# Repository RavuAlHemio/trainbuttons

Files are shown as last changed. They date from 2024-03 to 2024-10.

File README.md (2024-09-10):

# trainbuttons

Two boards providing buttons for controlling a train (simulator).

The buttons are provided by keyboard key switches (Cherry MX or compatible). The two boards are to be interconnected via a repurposed HDMI cable; the left board is then connected via USB-C to the computer.

The button layout is inspired by the results of the EUDDplus (European Driver's Desk plus) project and UIC 612. The icons are reconstructed from those in EN 16186-2. The buttons chosen are those supported, or expected to be supported, by the Zusi simulator.

The design does not include throttle or brake levers; potentiometer-based solutions are available from [Stillertec](https://fahrpult.com/).

The default firmware lets the device appear as a HID gamepad device with zero axes and 21 buttons. A debug pin header is provided on the board to allow installation of other firmware.

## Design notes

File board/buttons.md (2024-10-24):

| button | switch | µC pin | GPIO  | ADC channel | control |
| --- | --- | --- | ----- | ---:| ---:|
| NTC_ACK | SW203  | 12 | PA1 | | button 1  |
| HORN | SW306  | 13 | PA2 | | button 2  |
| BELL | SW307  | 14 | PA3 | | button 3  |
| TDIR_DN | SW305  | 15 | PA4 | | button 4  |
| BRAKE_SCHG | SW308  | 18 | PA7 | | button 5  |
| DOOR_OPEN  | SW211  | 37 | PA15  | | button 6  |
| TDIR_UP | SW304  | 20 | PB1 | | button 7  |
| HEADLIGHT  | SW303  | 21 | PB2 | | button 8  |
| DOOR_CLSE  | SW212  | 42 | PB3 | | button 9  |
| DOOR_LEFT  | SW209  | 43 | PB4 | | button 10 |
| MCB_OFF | SW208  | 44 | PB5 | | button 11 |
| EMERG | SW213  | 45 | PB6 | | button 12 |
| ETCS_ACK | SW204  | 46 | PB7 | | button 13 |
| NTC_OVR | SW201  | 47 | PB8 | | button 14 |
| NTC_RLS | SW202  | 48 | PB9 | | button 15 |
| BRAKE_RLS  | SW302  | 22 | PB10  | | button 16 |
| SAND | SW301  | 23 | PB11  | | button 17 |
| MCB_ON | SW207  | 38 | PD0 | | button 18 |
| PANTO_UP | SW205  | 39 | PD1 | | button 19 |
| PANTO_DN | SW206  | 40 | PD2 | | button 20 |
| DOOR_RGHT  | SW210  | 41 | PD3 | | button 21 |
| PEDAL_ANA  | J201 | 17 | PA6 | 6 | X axis |

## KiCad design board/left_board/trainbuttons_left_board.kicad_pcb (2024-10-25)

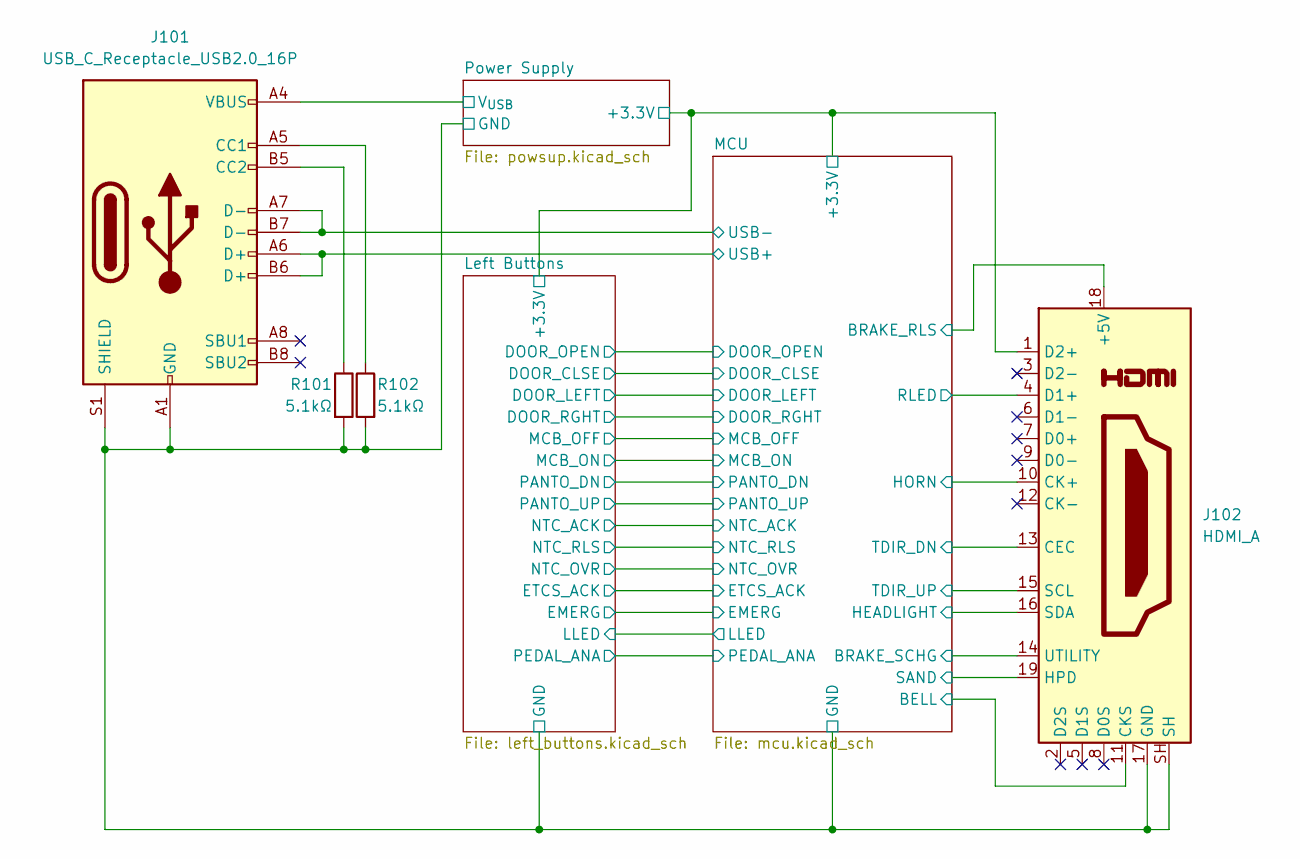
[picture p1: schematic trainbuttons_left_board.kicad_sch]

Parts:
J101: USB_C_Receptacle_USB2.0_16P; USB_C_Receptacle_G-Switch_GT-USB-7010ASV; LCSC C2988369
J102: HDMI_A; HDMI_A_Molex_208658-1001_Horizontal; LCSC C2858275
R101, R102: 5.1kΩ; R_0402_1005Metric; LCSC C25905

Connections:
/Left Buttons/+3.3V: J102.1 (D2+); also elsewhere on the board
/Left Buttons/GND: J101.A1 (GND), J101.A12 (GND), J101.B1 (GND), J101.B12 (GND), J101.S1 (SHIELD), J102.17 (GND), J102.SH, R101.2, R102.2; also elsewhere on the board
/MCU/BELL: J102.11 (CKS); also elsewhere on the board
/MCU/BRAKE_RLS: J102.18 (+5V); also elsewhere on the board
/MCU/BRAKE_SCHG: J102.14 (UTILITY); also elsewhere on the board
/MCU/HEADLIGHT: J102.16 (SDA); also elsewhere on the board
/MCU/HORN: J102.10 (CK+); also elsewhere on the board
/MCU/RLED: J102.4 (D1+); also elsewhere on the board
/MCU/SAND: J102.19 (HPD); also elsewhere on the board
/MCU/TDIR_DN: J102.13 (CEC); also elsewhere on the board
/MCU/TDIR_UP: J102.15 (SCL); also elsewhere on the board
/MCU/USB+: J101.A6 (D+), J101.B6 (D+); also elsewhere on the board
/MCU/USB-: J101.A7 (D-), J101.B7 (D-); also elsewhere on the board
/Power Supply/V_{USB}: J101.A4 (VBUS), J101.A9 (VBUS), J101.B4 (VBUS), J101.B9 (VBUS); also elsewhere on the board
unnamed: J101.A5 (CC1), R102.1
unnamed: J101.B5 (CC2), R101.1

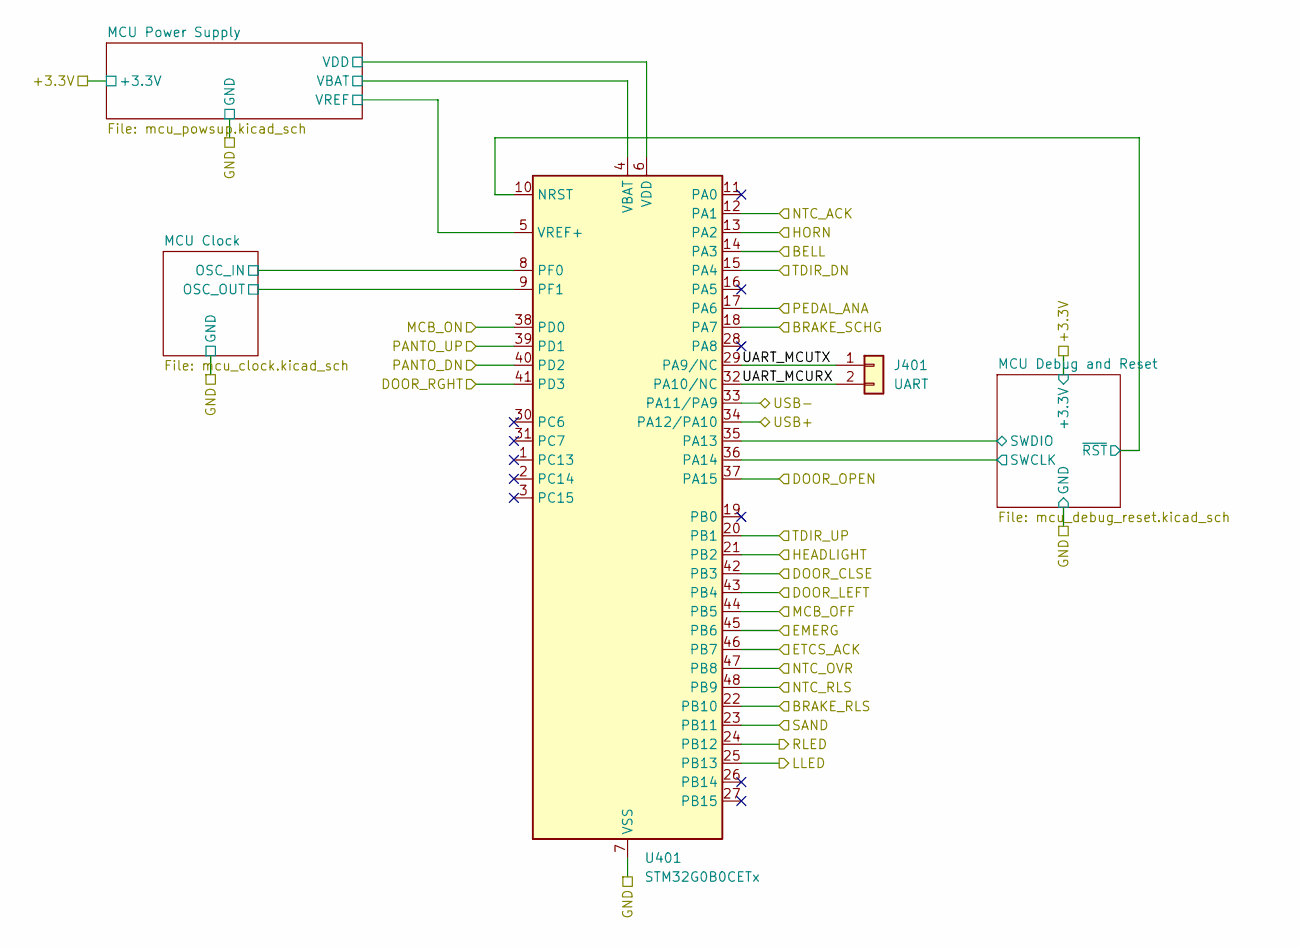
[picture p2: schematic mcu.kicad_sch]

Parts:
J401: UART; PinHeader_1x02_P2.54mm_Vertical_SMD_Pin1Left; LCSC C5160785
U401: STM32G0B0CETx; LQFP-48_7x7mm_P0.5mm; LCSC C2826978

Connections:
/Left Buttons/+3.3V: U401.4 (VBAT), U401.6 (VDD); also elsewhere on the board
/Left Buttons/DOOR_CLSE: U401.42 (PB3); also elsewhere on the board
/Left Buttons/DOOR_LEFT: U401.43 (PB4); also elsewhere on the board
/Left Buttons/DOOR_OPEN: U401.37 (PA15); also elsewhere on the board
/Left Buttons/DOOR_RGHT: U401.41 (PD3); also elsewhere on the board
/Left Buttons/EMERG: U401.45 (PB6); also elsewhere on the board
/Left Buttons/ETCS_ACK: U401.46 (PB7); also elsewhere on the board
/Left Buttons/GND: U401.7 (VSS); also elsewhere on the board
/Left Buttons/LLED: U401.25 (PB13); also elsewhere on the board
/Left Buttons/MCB_OFF: U401.44 (PB5); also elsewhere on the board
/Left Buttons/MCB_ON: U401.38 (PD0); also elsewhere on the board
/Left Buttons/NTC_ACK: U401.12 (PA1); also elsewhere on the board
/Left Buttons/NTC_OVR: U401.47 (PB8); also elsewhere on the board
/Left Buttons/NTC_RLS: U401.48 (PB9); also elsewhere on the board
/Left Buttons/PANTO_DN: U401.40 (PD2); also elsewhere on the board
/Left Buttons/PANTO_UP: U401.39 (PD1); also elsewhere on the board
/Left Buttons/PEDAL_ANA: U401.17 (PA6); also elsewhere on the board
/MCU/BELL: U401.14 (PA3); also elsewhere on the board
/MCU/BRAKE_RLS: U401.22 (PB10); also elsewhere on the board
/MCU/BRAKE_SCHG: U401.18 (PA7); also elsewhere on the board
/MCU/HEADLIGHT: U401.21 (PB2); also elsewhere on the board
/MCU/HORN: U401.13 (PA2); also elsewhere on the board
/MCU/MCU Clock/OSC_IN: U401.8 (PF0); also elsewhere on the board
/MCU/MCU Clock/OSC_OUT: U401.9 (PF1); also elsewhere on the board
/MCU/MCU Debug and Reset/SWCLK: U401.36 (PA14); also elsewhere on the board
/MCU/MCU Debug and Reset/SWDIO: U401.35 (PA13); also elsewhere on the board
/MCU/MCU Debug and Reset/~RST: U401.10 (NRST); also elsewhere on the board
/MCU/MCU Power Supply/VREF: U401.5 (VREF+); also elsewhere on the board
/MCU/RLED: U401.24 (PB12); also elsewhere on the board
/MCU/SAND: U401.23 (PB11); also elsewhere on the board
/MCU/TDIR_DN: U401.15 (PA4); also elsewhere on the board
/MCU/TDIR_UP: U401.20 (PB1); also elsewhere on the board
/MCU/UART_MCURX: J401.2, U401.32 (PA10/NC)
/MCU/UART_MCUTX: J401.1, U401.29 (PA9/NC)
/MCU/USB+: U401.34 (PA12/PA10); also elsewhere on the board
/MCU/USB-: U401.33 (PA11/PA9); also elsewhere on the board

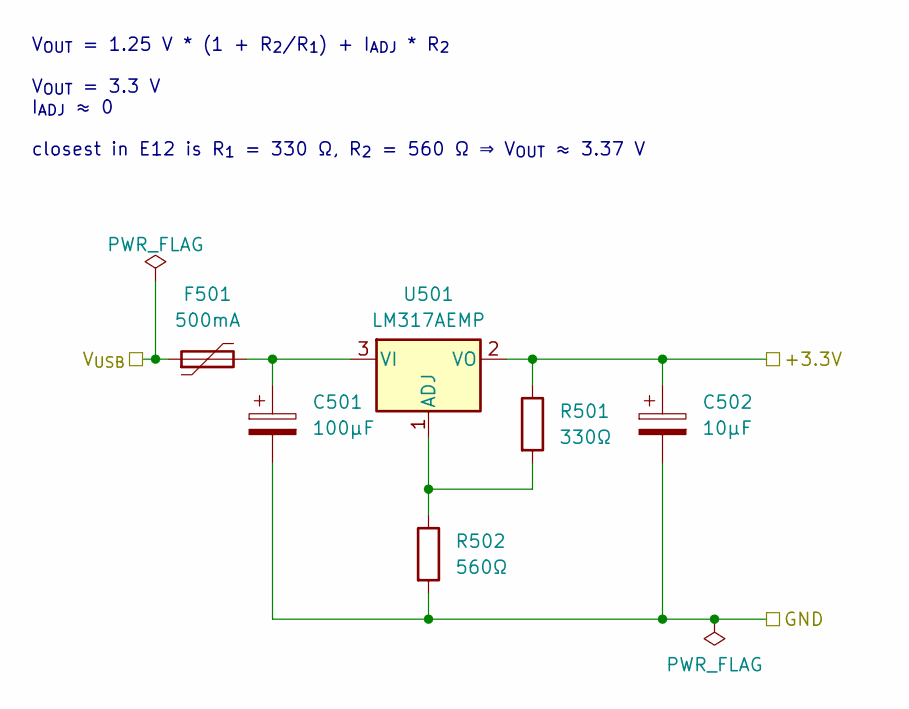
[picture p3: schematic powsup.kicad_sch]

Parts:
C501: 100µF; CP_EIA-3528-21_Kemet-B; LCSC C16133
C502: 10µF; CP_EIA-3216-18_Kemet-A; LCSC C7171
F501: 500mA; Fuse_0805_2012Metric; LCSC C2977522
R501: 330Ω; R_0603_1608Metric; LCSC C23138
R502: 560Ω; R_0603_1608Metric; LCSC C23204
U501: LM317AEMP; SOT-223-3_TabPin2; LCSC C33586

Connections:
/Left Buttons/+3.3V: C502.1, R501.1, U501.2 (VO); also elsewhere on the board
/Left Buttons/GND: C501.2, C502.2, R502.2; also elsewhere on the board
/Power Supply/V_{USB}: F501.1; also elsewhere on the board
unnamed: R501.2, R502.1, U501.1 (ADJ)
unnamed: C501.1, F501.2, U501.3 (VI)

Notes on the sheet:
V_{OUT} = 1.25 V * (1 + R_{2}/R_{1}) + I_{ADJ} * R_{2} V_{OUT} = 3.3 V I_{ADJ} ≈ 0 closest in E12 is R_{1} = 330 Ω, R_{2} = 560 Ω ⇒ V_{OUT} ≈ 3.37 V

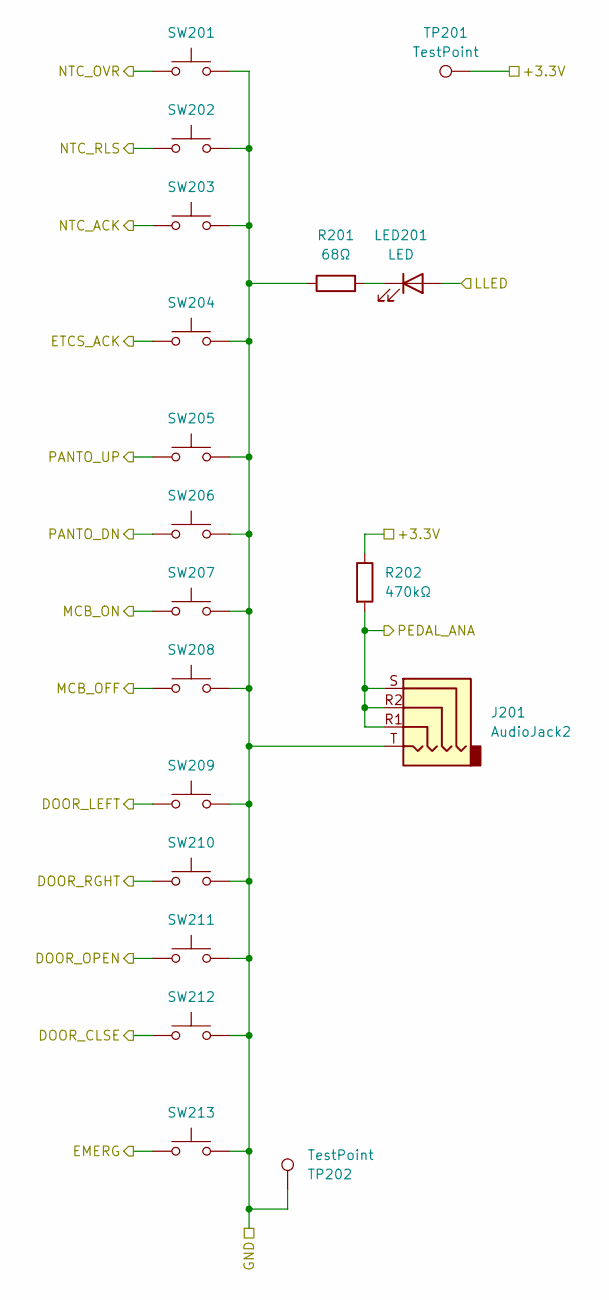
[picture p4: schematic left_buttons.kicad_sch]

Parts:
J201: AudioJack2; Jack_3.5mm_PJ320D_Horizontal; LCSC C431535
LED201: LED; LED_0805_2012Metric; LCSC C2296
R201: 68Ω; R_0805_2012Metric; LCSC C17802
R202: 470kΩ; R_0603_1608Metric; LCSC C23178
SW201, SW202, SW203, SW204, SW205, SW206, SW207, SW208, SW209, SW210, SW211, SW212, SW213: SW_Push; SW_Cherry_MX_1.00u_PCB
TP201, TP202: TestPoint; TestPoint_Pad_D1.0mm

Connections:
/Left Buttons/+3.3V: R202.1, TP201.1; also elsewhere on the board
/Left Buttons/DOOR_CLSE: SW212.1; also elsewhere on the board
/Left Buttons/DOOR_LEFT: SW209.1; also elsewhere on the board
/Left Buttons/DOOR_OPEN: SW211.1; also elsewhere on the board
/Left Buttons/DOOR_RGHT: SW210.1; also elsewhere on the board
/Left Buttons/EMERG: SW213.1; also elsewhere on the board
/Left Buttons/ETCS_ACK: SW204.1; also elsewhere on the board
/Left Buttons/GND: J201.T, R201.1, SW201.2, SW202.2, SW203.2, SW204.2, SW205.2, SW206.2, SW207.2, SW208.2, SW209.2, SW210.2, SW211.2, SW212.2, SW213.2, TP202.1; also elsewhere on the board
/Left Buttons/LLED: LED201.2 (A); also elsewhere on the board
/Left Buttons/MCB_OFF: SW208.1; also elsewhere on the board
/Left Buttons/MCB_ON: SW207.1; also elsewhere on the board
/Left Buttons/NTC_ACK: SW203.1; also elsewhere on the board
/Left Buttons/NTC_OVR: SW201.1; also elsewhere on the board
/Left Buttons/NTC_RLS: SW202.1; also elsewhere on the board
/Left Buttons/PANTO_DN: SW206.1; also elsewhere on the board
/Left Buttons/PANTO_UP: SW205.1; also elsewhere on the board
/Left Buttons/PEDAL_ANA: J201.R1, J201.R2, J201.S, R202.2; also elsewhere on the board
unnamed: LED201.1 (K), R201.2

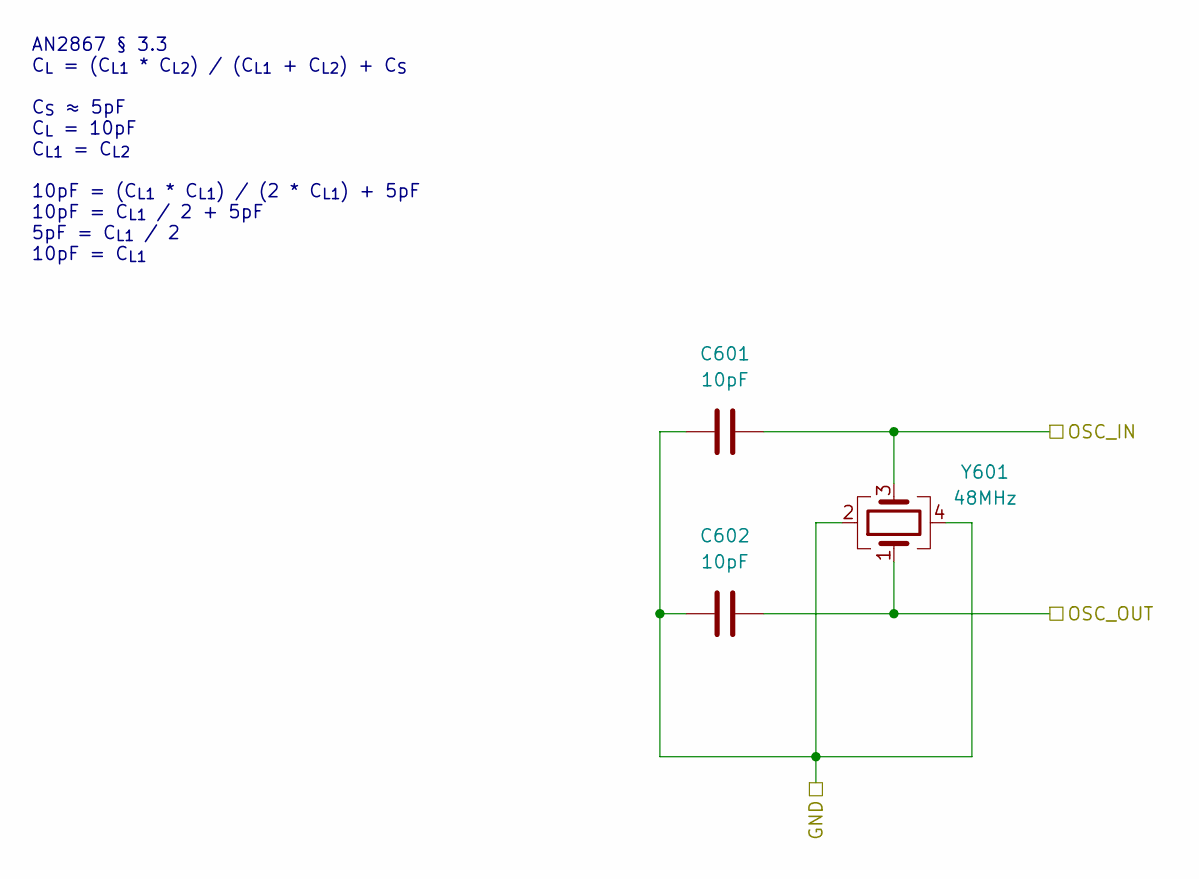
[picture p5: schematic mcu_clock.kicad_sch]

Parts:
C601, C602: 10pF; C_0402_1005Metric; LCSC C32949
Y601: 48MHz; Crystal_SMD_2016-4Pin_2.0x1.6mm; LCSC C648978

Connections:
/Left Buttons/GND: C601.1, C602.1, Y601.2, Y601.4; also elsewhere on the board
/MCU/MCU Clock/OSC_IN: C601.2, Y601.3; also elsewhere on the board
/MCU/MCU Clock/OSC_OUT: C602.2, Y601.1; also elsewhere on the board

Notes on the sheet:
AN2867 § 3.3 C_{L} = (C_{L1} * C_{L2}) / (C_{L1} + C_{L2}) + C_{S} C_{S} ≈ 5pF C_{L} = 10pF C_{L1} = C_{L2} 10pF = (C_{L1} * C_{L1}) / (2 * C_{L1}) + 5pF 10pF = C_{L1} / 2 + 5pF 5pF = C_{L1} / 2 10pF = C_{L1}

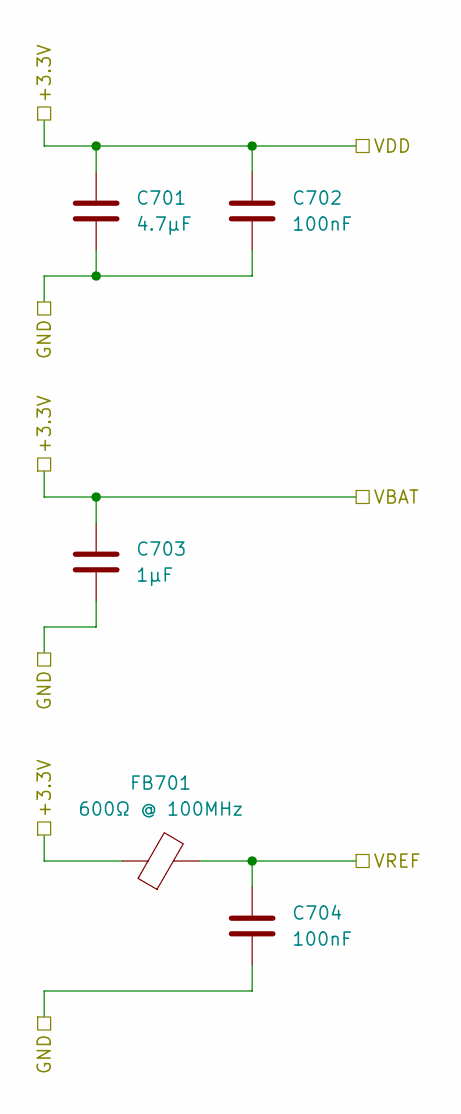
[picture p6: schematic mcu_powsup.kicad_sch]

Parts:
C701: 4.7μF; C_0402_1005Metric; LCSC C23733
C702, C704: 100nF; C_0402_1005Metric; LCSC C307331
C703: 1μF; C_0402_1005Metric; LCSC C52923
FB701: 600Ω @ 100MHz; L_0402_1005Metric; LCSC C560060

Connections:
/Left Buttons/+3.3V: C701.1, C702.1, C703.1, FB701.1; also elsewhere on the board
/Left Buttons/GND: C701.2, C702.2, C703.2, C704.2; also elsewhere on the board
/MCU/MCU Power Supply/VREF: C704.1, FB701.2; also elsewhere on the board

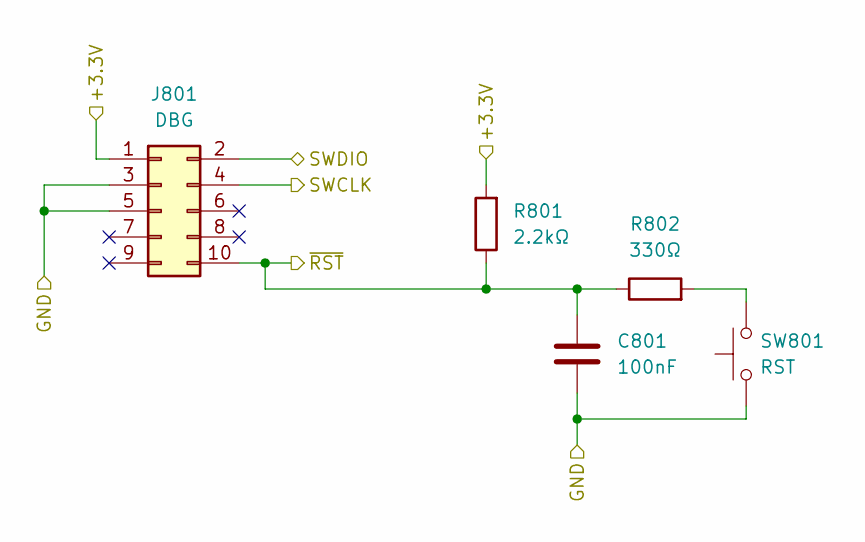
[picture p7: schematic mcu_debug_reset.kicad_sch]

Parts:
C801: 100nF; C_0402_1005Metric; LCSC C307331
J801: DBG; PinHeader_2x05_P1.27mm_Vertical_SMD; LCSC C5250218
R801: 2.2kΩ; R_0402_1005Metric; LCSC C25879
R802: 330Ω; R_0402_1005Metric; LCSC C25104
SW801: RST; SW_Push_1P1T_XKB_TS-1187A; LCSC C318884

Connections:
/Left Buttons/+3.3V: J801.1, R801.2; also elsewhere on the board
/Left Buttons/GND: C801.1, J801.3, J801.5, SW801.1; also elsewhere on the board
/MCU/MCU Debug and Reset/SWCLK: J801.4; also elsewhere on the board
/MCU/MCU Debug and Reset/SWDIO: J801.2; also elsewhere on the board
/MCU/MCU Debug and Reset/~RST: C801.2, J801.10, R801.1, R802.1; also elsewhere on the board
unnamed: R802.2, SW801.2

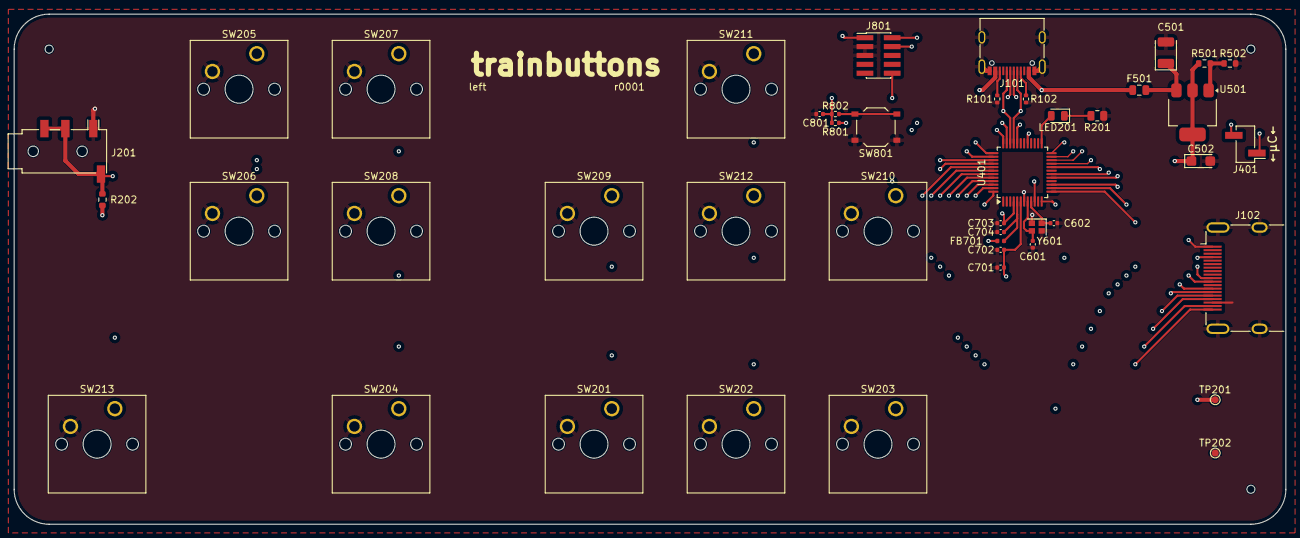
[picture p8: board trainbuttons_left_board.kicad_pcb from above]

Board: 4 copper layers, 182.0 x 73.0 mm, 44 parts (0 on the bottom side), 43 nets.

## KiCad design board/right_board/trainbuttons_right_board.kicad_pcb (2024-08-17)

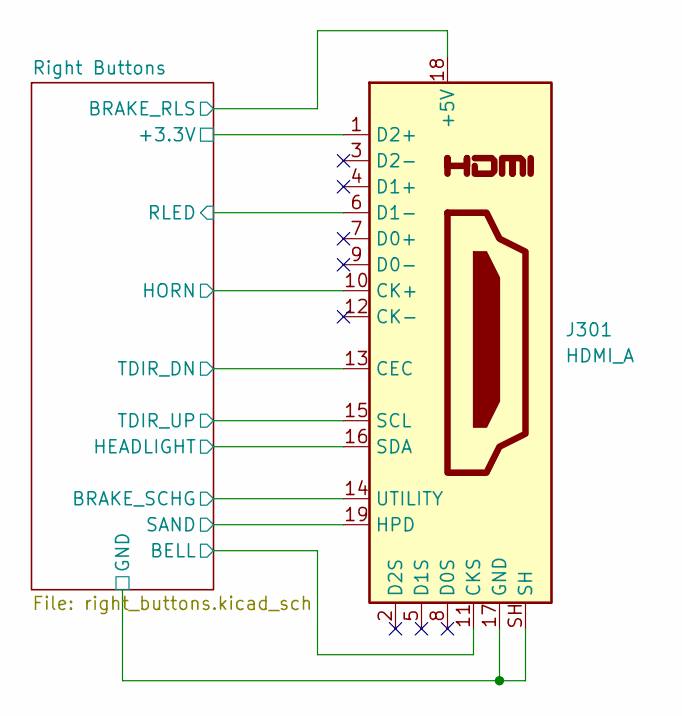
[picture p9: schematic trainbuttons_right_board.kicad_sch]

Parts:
J301: HDMI_A; HDMI_A_Molex_208658-1001_Horizontal; LCSC C2858275

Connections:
/Right Buttons/+3.3V: J301.1 (D2+); also elsewhere on the board
/Right Buttons/BELL: J301.11 (CKS); also elsewhere on the board
/Right Buttons/BRAKE_RLS: J301.18 (+5V); also elsewhere on the board
/Right Buttons/BRAKE_SCHG: J301.14 (UTILITY); also elsewhere on the board
/Right Buttons/GND: J301.17 (GND), J301.SH; also elsewhere on the board
/Right Buttons/HEADLIGHT: J301.16 (SDA); also elsewhere on the board
/Right Buttons/HORN: J301.10 (CK+); also elsewhere on the board
/Right Buttons/RLED: J301.6 (D1-); also elsewhere on the board
/Right Buttons/SAND: J301.19 (HPD); also elsewhere on the board
/Right Buttons/TDIR_DN: J301.13 (CEC); also elsewhere on the board
/Right Buttons/TDIR_UP: J301.15 (SCL); also elsewhere on the board

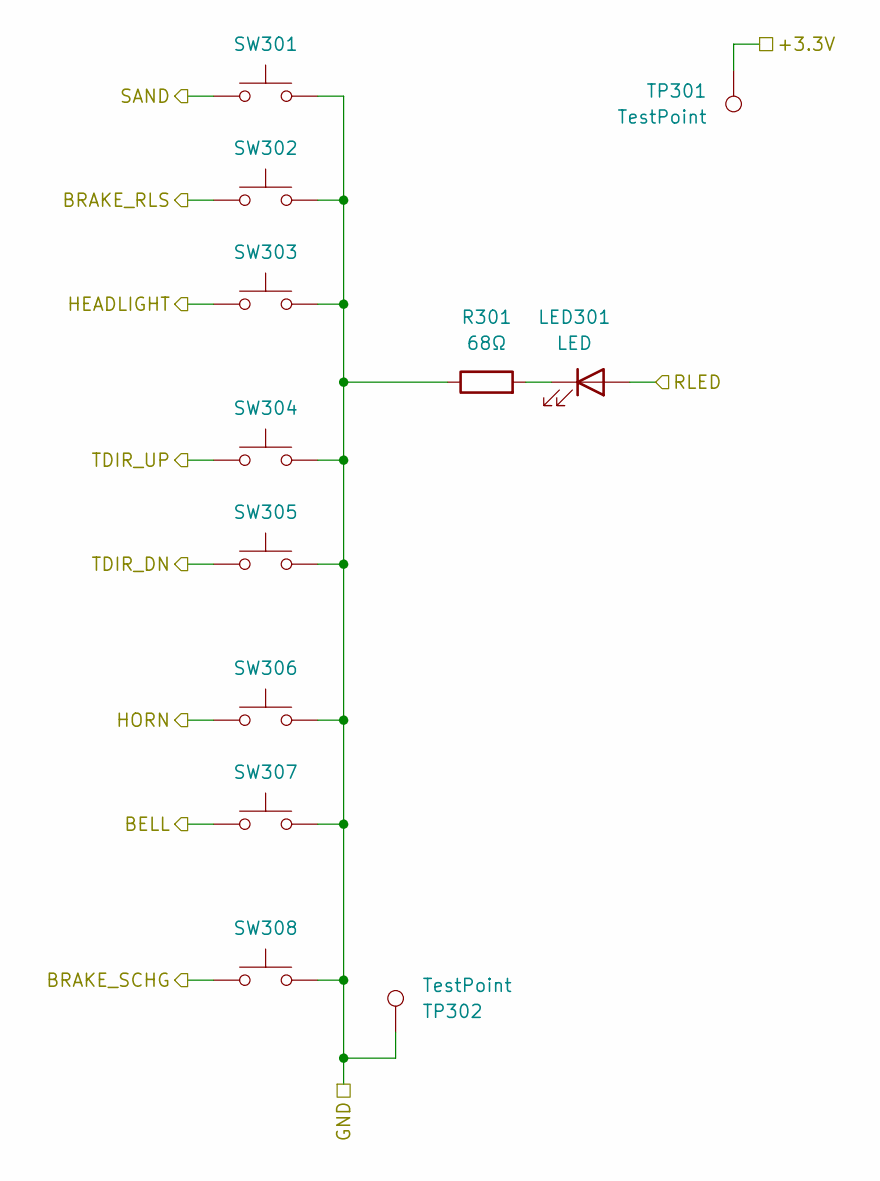
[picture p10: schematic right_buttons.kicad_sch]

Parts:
LED301: LED; LED_0805_2012Metric; LCSC C2296
R301: 68Ω; R_0805_2012Metric; LCSC C17802
SW301, SW302, SW303, SW304, SW305, SW306, SW307, SW308: SW_Push; SW_Cherry_MX_1.00u_PCB
TP301, TP302: TestPoint; TestPoint_Pad_D1.0mm

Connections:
/Right Buttons/+3.3V: TP301.1; also elsewhere on the board
/Right Buttons/BELL: SW307.1; also elsewhere on the board
/Right Buttons/BRAKE_RLS: SW302.1; also elsewhere on the board
/Right Buttons/BRAKE_SCHG: SW308.1; also elsewhere on the board
/Right Buttons/GND: R301.1, SW301.2, SW302.2, SW303.2, SW304.2, SW305.2, SW306.2, SW307.2, SW308.2, TP302.1; also elsewhere on the board
/Right Buttons/HEADLIGHT: SW303.1; also elsewhere on the board
/Right Buttons/HORN: SW306.1; also elsewhere on the board
/Right Buttons/RLED: LED301.2 (A); also elsewhere on the board
/Right Buttons/SAND: SW301.1; also elsewhere on the board
/Right Buttons/TDIR_DN: SW305.1; also elsewhere on the board
/Right Buttons/TDIR_UP: SW304.1; also elsewhere on the board
unnamed: LED301.1 (K), R301.2

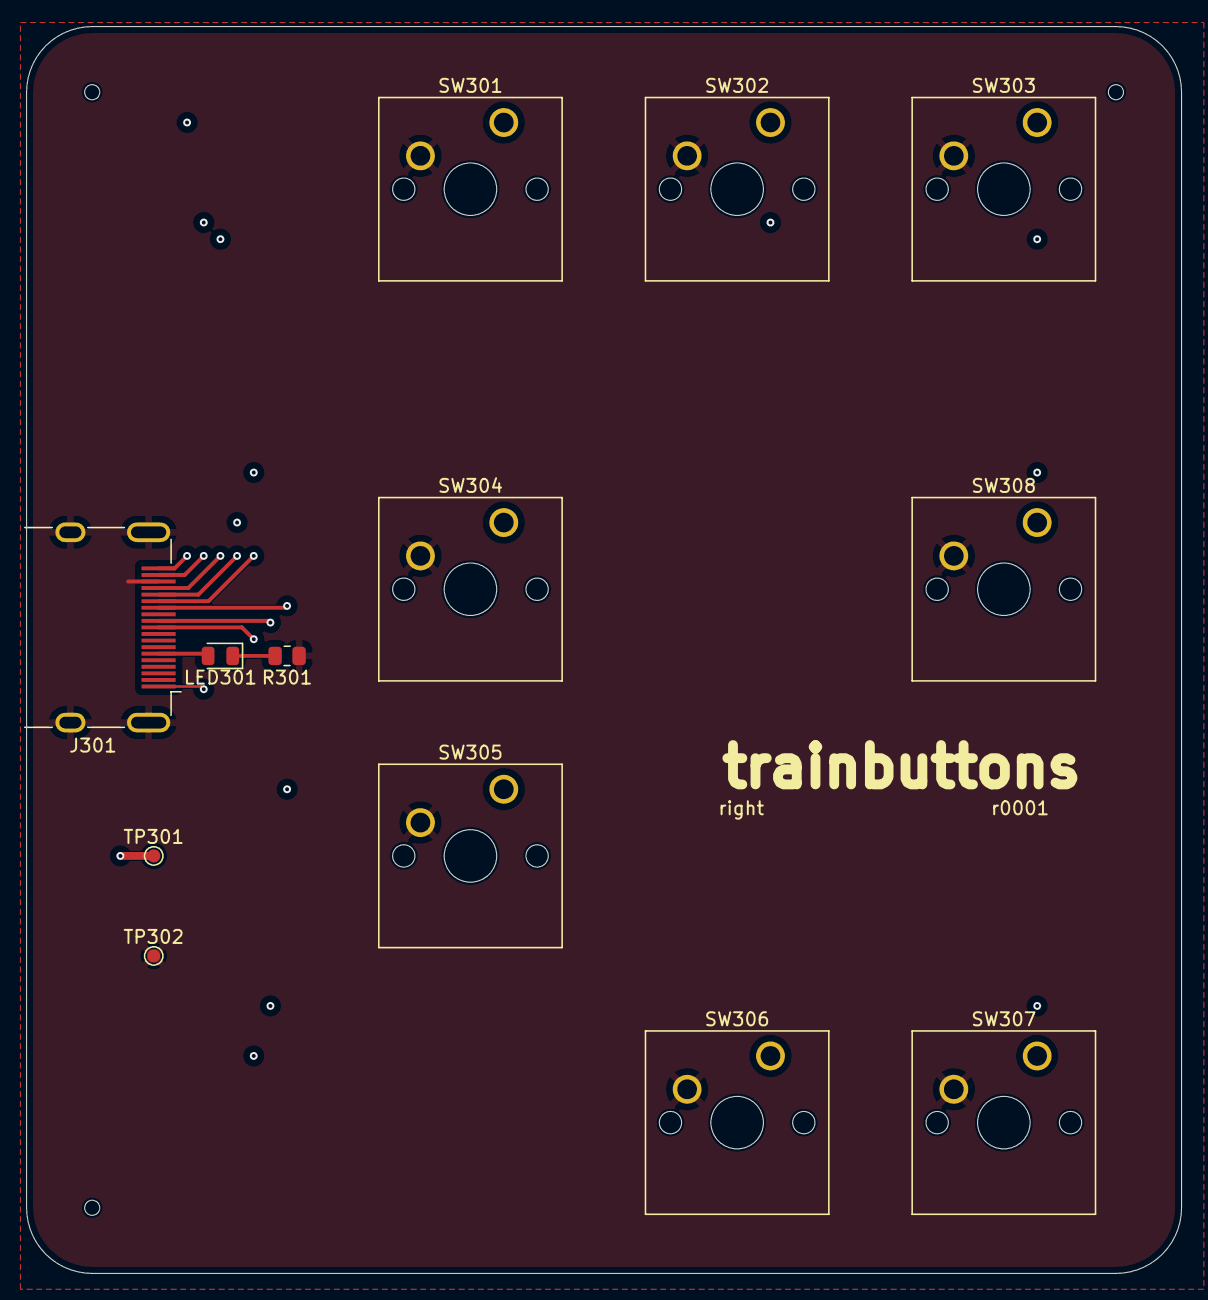
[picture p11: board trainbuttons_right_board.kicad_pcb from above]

Board: 4 copper layers, 88.0 x 95.0 mm, 13 parts (0 on the bottom side), 12 nets.

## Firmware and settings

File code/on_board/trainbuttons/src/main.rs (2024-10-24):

#![no_std]
#![no_main]


mod adc;
mod clock;
mod pins;
mod uart;
mod usb;


use core::panic::PanicInfo;

use cortex_m_rt::entry;
use stm32g0b0::Peripherals;


#[panic_handler]
fn panic_handler(_panic_info: &PanicInfo) -> ! {
    loop {
    }
}


#[inline(never)]
fn tell_gdb_to_return_from_this_function() {
    // address 4 (reset interrupt) is never 1
    const RESET_INTERRUPT_PTR: *const u32 = 0x0000_0004 as *const u32;
    loop {
        let isvp = unsafe { core::ptr::read_volatile(RESET_INTERRUPT_PTR) };
        if isvp == 1 {
            return;
        }
    }
}


#[entry]
fn main() -> ! {
    let peripherals = unsafe { Peripherals::steal() };

    crate::clock::set_up(&peripherals);

    // disable pulldowns
    peripherals.syscfg.cfgr1().modify(|_, w| w
        .ucpd1_strobe().set_bit() // disable pulldowns on PA8 and PB15
        .ucpd2_strobe().set_bit() // disable pulldowns on PD0 and PD2
    );

    // send clock to all relevant peripherals
    crate::adc::enable_peripheral_clocks(&peripherals);
    crate::pins::enable_peripheral_clocks(&peripherals);
    crate::uart::enable_peripheral_clocks(&peripherals);
    crate::usb::enable_peripheral_clocks(&peripherals);

    // reset all relevant peripherals
    crate::adc::start_reset(&peripherals);
    crate::pins::start_reset(&peripherals);
    crate::uart::start_reset(&peripherals);
    crate::usb::start_reset(&peripherals);
    // give it a bit to reset
    for _ in 0..64 {
        cortex_m::asm::nop();
    }
    crate::adc::stop_reset(&peripherals);
    crate::pins::stop_reset(&peripherals);
    crate::uart::stop_reset(&peripherals);
    crate::usb::stop_reset(&peripherals);
    // give it a bit to reinitialize
    for _ in 0..64 {
        cortex_m::asm::nop();
    }

    // set up pins (buttons and LEDs)
    crate::pins::set_up(&peripherals);

    // turn on LED on other board
    peripherals.gpiob.bsrr().write(|w| w
        .bs12().set_bit()
    );

    // set up ADC, UART and USB
    crate::adc::set_up(&peripherals);
    crate::uart::set_up(&peripherals);
    crate::usb::set_up(&peripherals);

    // send initial data via UART
    crate::uart::write_bytes(&peripherals, b"\r\nHi, world!\r\n");

    /*
    // disable USB IRQ so we can poke around
    cortex_m::peripheral::NVIC::mask(stm32g0b0::Interrupt::USB);
    tell_gdb_to_return_from_this_function();
    */

    loop {
        cortex_m::asm::wfe();
    }
}

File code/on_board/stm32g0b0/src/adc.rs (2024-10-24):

#[repr(C)]
#[doc = "Register block"]
pub struct RegisterBlock {
    isr: Isr,
    ier: Ier,
    cr: Cr,
    cfgr1: Cfgr1,
    cfgr2: Cfgr2,
    smpr: Smpr,
    _reserved6: [u8; 0x08],
    awd1tr: Awd1tr,
    awd2tr: Awd2tr,
    _reserved_8_chselr_: [u8; 0x04],
    awd3tr: Awd3tr,
    _reserved10: [u8; 0x10],
    dr: Dr,
    _reserved11: [u8; 0x5c],
    awd2cr: Awd2cr,
    awd3cr: Awd3cr,
    _reserved13: [u8; 0x0c],
    calfact: Calfact,
    _reserved14: [u8; 0x0250],
    ccr: Ccr,
}
impl RegisterBlock {
    #[doc = "0x00 - ADC interrupt and status register"]
    #[inline(always)]
    pub const fn isr(&self) -> &Isr {
        &self.isr
    }
    #[doc = "0x04 - ADC interrupt enable register"]
    #[inline(always)]
    pub const fn ier(&self) -> &Ier {
        &self.ier
    }
    #[doc = "0x08 - ADC control register"]
    #[inline(always)]
    pub const fn cr(&self) -> &Cr {
        &self.cr
    }
    #[doc = "0x0c - ADC configuration register 1"]
    #[inline(always)]
    pub const fn cfgr1(&self) -> &Cfgr1 {
        &self.cfgr1
    }
    #[doc = "0x10 - ADC configuration register 2"]
    #[inline(always)]
    pub const fn cfgr2(&self) -> &Cfgr2 {
        &self.cfgr2
    }
    #[doc = "0x14 - ADC sampling time register"]
    #[inline(always)]
    pub const fn smpr(&self) -> &Smpr {
        &self.smpr
    }
    #[doc = "0x20 - ADC watchdog threshold register"]
    #[inline(always)]
    pub const fn awd1tr(&self) -> &Awd1tr {
        &self.awd1tr
    }
    #[doc = "0x24 - ADC watchdog threshold register"]
    #[inline(always)]
    pub const fn awd2tr(&self) -> &Awd2tr {
        &self.awd2tr
    }
    #[doc = "0x28 - channel selection register CHSELRMOD = 1 in ADC_CFGR1"]
    #[inline(always)]
    pub const fn chselr_1(&self) -> &Chselr1 {
        unsafe { &*(self as *const Self).cast::<u8>().add(40).cast() }
    }
    #[doc = "0x28 - ADC channel selection register \\[alternate\\]"]
    #[inline(always)]
    pub const fn chselr_0(&self) -> &Chselr0 {
        unsafe { &*(self as *const Self).cast::<u8>().add(40).cast() }
    }
    #[doc = "0x2c - ADC watchdog threshold register"]
    #[inline(always)]
    pub const fn awd3tr(&self) -> &Awd3tr {
        &self.awd3tr
    }
    #[doc = "0x40 - ADC data register"]
    #[inline(always)]
    pub const fn dr(&self) -> &Dr {
        &self.dr
    }
    #[doc = "0xa0 - ADC Analog Watchdog 2 Configuration register"]
    #[inline(always)]
    pub const fn awd2cr(&self) -> &Awd2cr {
        &self.awd2cr
    }
    #[doc = "0xa4 - ADC Analog Watchdog 3 Configuration register"]
    #[inline(always)]
    pub const fn awd3cr(&self) -> &Awd3cr {
        &self.awd3cr
    }
    #[doc = "0xb4 - ADC Calibration factor"]
    #[inline(always)]
    pub const fn calfact(&self) -> &Calfact {
        &self.calfact
    }
    #[doc = "0x308 - ADC common configuration register"]
    #[inline(always)]
    pub const fn ccr(&self) -> &Ccr {
        &self.ccr
    }
}
#[doc = "ISR (rw) register accessor: ADC interrupt and status register\n\nYou can [`read`](crate::Reg::read) this register and get [`isr::R`]. You can [`reset`](crate::Reg::reset), [`write`](crate::Reg::write), [`write_with_zero`](crate::Reg::write_with_zero) this register using [`isr::W`]. You can also [`modify`](crate::Reg::modify) this register. See [API](https://docs.rs/svd2rust/#read--modify--write-api).\n\nFor information about available fields see [`mod@isr`]
module"]
#[doc(alias = "ISR")]
pub type Isr = crate::Reg<isr::IsrSpec>;
#[doc = "ADC interrupt and status register"]
pub mod isr;
#[doc = "IER (rw) register accessor: ADC interrupt enable register\n\nYou can [`read`](crate::Reg::read) this register and get [`ier::R`]. You can [`reset`](crate::Reg::reset), [`write`](crate::Reg::write), [`write_with_zero`](crate::Reg::write_with_zero) this register using [`ier::W`]. You can also [`modify`](crate::Reg::modify) this register. See [API](https://docs.rs/svd2rust/#read--modify--write-api).\n\nFor information about available fields see [`mod@ier`]
module"]
#[doc(alias = "IER")]
pub type Ier = crate::Reg<ier::IerSpec>;
#[doc = "ADC interrupt enable register"]
pub mod ier;
#[doc = "CR (rw) register accessor: ADC control register\n\nYou can [`read`](crate::Reg::read) this register and get [`cr::R`]. You can [`reset`](crate::Reg::reset), [`write`](crate::Reg::write), [`write_with_zero`](crate::Reg::write_with_zero) this register using [`cr::W`]. You can also [`modify`](crate::Reg::modify) this register. See [API](https://docs.rs/svd2rust/#read--modify--write-api).\n\nFor information about available fields see [`mod@cr`]
module"]
#[doc(alias = "CR")]
pub type Cr = crate::Reg<cr::CrSpec>;
#[doc = "ADC control register"]
pub mod cr;
#[doc = "CFGR1 (rw) register accessor: ADC configuration register 1\n\nYou can [`read`](crate::Reg::read) this register and get [`cfgr1::R`]. You can [`reset`](crate::Reg::reset), [`write`](crate::Reg::write), [`write_with_zero`](crate::Reg::write_with_zero) this register using [`cfgr1::W`]. You can also [`modify`](crate::Reg::modify) this register. See [API](https://docs.rs/svd2rust/#read--modify--write-api).\n\nFor information about available fields see [`mod@cfgr1`]
module"]
#[doc(alias = "CFGR1")]
pub type Cfgr1 = crate::Reg<cfgr1::Cfgr1Spec>;
#[doc = "ADC configuration register 1"]
pub mod cfgr1;
#[doc = "CFGR2 (rw) register accessor: ADC configuration register 2\n\nYou can [`read`](crate::Reg::read) this register and get [`cfgr2::R`]. You can [`reset`](crate::Reg::reset), [`write`](crate::Reg::write), [`write_with_zero`](crate::Reg::write_with_zero) this register using [`cfgr2::W`]. You can also [`modify`](crate::Reg::modify) this register. See [API](https://docs.rs/svd2rust/#read--modify--write-api).\n\nFor information about available fields see [`mod@cfgr2`]
module"]
#[doc(alias = "CFGR2")]
pub type Cfgr2 = crate::Reg<cfgr2::Cfgr2Spec>;
#[doc = "ADC configuration register 2"]
pub mod cfgr2;
#[doc = "SMPR (rw) register accessor: ADC sampling time register\n\nYou can [`read`](crate::Reg::read) this register and get [`smpr::R`]. You can [`reset`](crate::Reg::reset), [`write`](crate::Reg::write), [`write_with_zero`](crate::Reg::write_with_zero) this register using [`smpr::W`]. You can also [`modify`](crate::Reg::modify) this register. See [API](https://docs.rs/svd2rust/#read--modify--write-api).\n\nFor information about available fields see [`mod@smpr`]
module"]
#[doc(alias = "SMPR")]
pub type Smpr = crate::Reg<smpr::SmprSpec>;
#[doc = "ADC sampling time register"]
pub mod smpr;
#[doc = "AWD1TR (rw) register accessor: ADC watchdog threshold register\n\nYou can [`read`](crate::Reg::read) this register and get [`awd1tr::R`]. You can [`reset`](crate::Reg::reset), [`write`](crate::Reg::write), [`write_with_zero`](crate::Reg::write_with_zero) this register using [`awd1tr::W`]. You can also [`modify`](crate::Reg::modify) this register. See [API](https://docs.rs/svd2rust/#read--modify--write-api).\n\nFor information about available fields see [`mod@awd1tr`]
module"]
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

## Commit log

2024-03-31 initial commit (WIP board)
    [left_buttons.kicad_sch, mcu.kicad_sch, mcu_clock.kicad_sch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]
2024-03-31 add initial code (autogenerated stm32g0b0)
2024-04-21 split board into left and right
    [left_buttons.kicad_sch, mcu.kicad_sch, mcu_clock.kicad_sch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]
2024-04-22 boards: add JLCPCB mounting holes
    [trainbuttons_left_board.kicad_pcb, trainbuttons_right_board.kicad_pcb]
2024-04-23 add button layout SVG
2024-04-23 button_layout: add standardized icons, start tracing them
2024-04-24 button_layout: trace more button icons
2024-04-24 button_layout: finish tracing icons
2024-08-04 schematics: trailing newlines
    [left_buttons.kicad_sch, mcu.kicad_sch, mcu_clock.kicad_sch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]
2024-08-04 left board: fix cap: 4.7nF -> 4.7µF
    [mcu_powsup.kicad_sch]
2024-08-04 board: PCB updates
    [trainbuttons_left_board.kicad_pcb, trainbuttons_right_board.kicad_pcb]
2024-08-04 USB interrupt is 8
    this has been confirmed by ST in case 00202361
2024-08-04 stm32g0b0: add USB RAM1
2024-08-04 stm32g0b0: re-export cortex_m_rt::interrupt
2024-08-04 build scripts
    [oocd-prog-jlink.cfg]
2024-08-05 stm32g0b0: regenerate using svd2rust 0.33.4
2024-08-05 stm32g0b0: mark some USB_RAM registers as safe
2024-08-05 stm32g0b0: USB quality-of-life improvements
2024-08-06 stm32g0b0: USB endpoint registers as array
2024-08-09 stm32g0b0 usb: CHEPR -> CHEPNR
    optimally, the registers would be named CHEP0R, CHEP1R etc., but that doesn't work syntactically
    call them CHEPNR because that's a string that can be found in the relevant manuals
2024-08-09 stm32g0b0: make usb.daddr.add settable to any value
2024-08-11 add code for debugging
    [oocd-debug-jlink.cfg]
2024-08-13 they lied to me
    USBSEL documentation is wrong. ST case 00212654 is open.
2024-08-13 stm32g0b0: more enumerated values -- we like our creature comforts
2024-08-13 stm32g0b0: make some USB_CHEPnR fields readable too
    their bits are "write 1 to toggle", so reading them is necessary when
    wanting to set them to a specific value
2024-08-15 usb: no more blinky when interrupt is hit
2024-08-17 stm32g0b0: add USART creature comforts
2024-08-17 implement UART
2024-08-17 left: replace UART pin header
    choose a 2.54mm variant that can be mounted easily
    [mcu.kicad_sch, trainbuttons_left_board.kicad_pcb]
2024-08-17 left: add no-connects to MCU
    [mcu.kicad_sch, trainbuttons_left_board.kicad_pcb]
2024-08-17 right: add revision text
    [trainbuttons_right_board.kicad_pcb]
2024-08-19 uart: also configure GPIO
2024-08-19 uart: hex dumping
2024-08-19 usb: take USB interrupt handlers from HAL code
2024-08-19 main: greet the world via UART
2024-08-25 stm32g0b0: dimIncrement is in bytes, not bits
2024-10-24 group "enable clock", "start reset" and "stop reset" per peripheral
    this makes it more straightforward to light up new peripherals later on
    [main.rs, pins.rs, uart.rs]
2024-10-24 move button state reading to the pins module
2024-10-24 stm32g0b0: ADC.CFGR2.CKMODE option beautification
2024-10-24 stm32g0b0: ADC.CFGR1.CHSELRMOD option beautification
2024-10-24 stm32g0b0: ADC.CFGR1.SCANDIR option beautification
2024-10-24 stm32g0b0: remove DMA_ prefix from registers of DMA peripheral
2024-10-24 stm32g0b0: merge DMAx.CPARx register definitions
2024-10-24 stm32g0b0: make DMAx.CPARx.PA settable to direct values
2024-10-24 stm32g0b0: merge DMAx.CMARx register definitions
2024-10-24 stm32g0b0: make DMAx.CMARx.MA settable to direct values
2024-10-24 stm32g0b0: merge DMAx.CNDTRx register definitions
2024-10-24 stm32g0b0: make DMAx.CNDTRx.NDT settable to direct values
2024-10-24 stm32g0b0: merge DMAx.CCRx register definitions
2024-10-24 stm32g0b0: DMAx.CCRx.PL option beautification
2024-10-24 stm32g0b0: DMAx.CCRx.DIR option beautification
2024-10-24 stm32g0b0: DMAx.CCRx.(PSIZE|MSIZE) option beautification
2024-10-24 stm32g0b0: remove DMAMUX_ prefix from registers of DMAMUX peripheral
2024-10-24 stm32g0b0: merge DMAMUX.(CxCR|RGxCR) register definitions
2024-10-24 stm32g0b0: widen DMAMUX.CxCR.DMAREQ_ID to 7 bits, add options
2024-10-24 stm32g0b0: ADC.CFGR1.EXTEN option beautification
2024-10-24 stm32g0b0: ADC.CFGR1.RES option beautification
2024-10-24 stm32g0b0: ADC.CFGR1.ALIGN option beautification
2024-10-24 stm32g0b0: ADC.CFGR1.DMACFG option beautification
2024-10-24 add support for pedal
    the pedal is mostly envisioned as a secondary dead man's switch input, but
    to enable flexible usage, it is wired up to the µC's ADC and supplies
    12-bit values for the X axis
    things will be set up to cooperate with a Brother-compatible sewing machine
    pedal because that's what I have lying around -- those that connect using a
    3.5mm TS phone connector, nothing even close to mains voltage
    [left_buttons.kicad_sch, mcu.kicad_sch, trainbuttons_left_board.kicad_pcb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]
2024-10-24 stm32g0b0: remove ADC_ prefix from registers of ADC peripheral
2024-10-25 left board: pullup resistor for pedal
    [left_buttons.kicad_sch, trainbuttons_left_board.kicad_pcb]
